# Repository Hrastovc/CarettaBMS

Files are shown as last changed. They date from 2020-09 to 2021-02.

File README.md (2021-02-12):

# CarettaBMS

CarettaBMS is the best price to performance battery management system and it's also open-source.

# Overview

In recent years, there has been an increase in the use of ultralight electric vehicles. A fairly new segment requires the use of smaller battery packs for energy storage to power vehicles. For safe use of battery packs, BMS is very important. There is a big shortage in the field of quality battery management systems, which would be suitable for smaller battery packs. Prices of the systems currently on the market are too high. The price of a BMS can exceed the price of a battery pack. The use of such BMS does not make sense. The most difficult task was to make the system as inexpensive as possible for use with smaller battery packs. Despite the low cost, BMS still has all the necessary safety mechanisms.

By approaching the challenges in a creative way it was possible to find an innovative solutions, which enabled a very low-cost implementation of the system. Analog to digital converter (ADC) is used with swapped inputs reference and ADC input. This makes it possible to measure the supply voltage without the use a of voltage divider and additional static energy consumption a voltage divider would entail. The type A standard uncertainty of cell voltage measurement is 0.9 mV. The communication uses a built-in analog comparator and two external resistors. Despite the fact that series connected modules operate on different reference potentials, this does not affect the message transmission. Tests with artificially induced interference confirmed the communication reliability of an arbitrary number of modules connected in series.

The work was released as an open source project with the name CarettaBMS. The purpose is to allow access to better quality BMS suitable for smaller battery packs to a wider audience.

# System Arhitecure

System Arhitecure

# specifications

 - Operating voltage range: od 1.8V do 5.0V
 - Operating temperature range: od 0°C do 80°C
 - Voltage measurement accuracy: ±10mV
 - Voltage measurement resolution: at least 3mV
 - Temperature measurement accuracy: ±5°C
 - PCB size: 65mm × 18mm × 5mm
 - Passive cell balancing current: 1A
 - load characteristics: R = 3.6Ω, P<sub>max</sub> = 4W
 - Maximum of series connected cells: up to 256
 - Temperature sensors: at least 3 sensors per module (1 internal, 2 external)
or up to 32 I2C sensors
 - Communication interface (cell modules with master): isolated UART 8E2
(documented protocol)
 - Bootloader for future infield firmware upgrades

# Cell Module
Cell module PCB

Schematic: https://github.com/Hrastovc/CarettaBMS/blob/master/CellModule/Hardware/CarettaBMS_CellModule0v8.pdf

# License

CarettaBMS is free software: you can redistribute it and/or modify it under the terms of the GNU General Public License version 3 as published by the Free Software Foundation.

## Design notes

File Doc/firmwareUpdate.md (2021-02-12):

---
filename: 03_firmwareUpdate
title: Firmware update
layout: main
---

To enter the bootloader send 0x62 (on 8N1 or 8E2) until you receive 0xEB response or until now response is received. To test if the mouldes are in the bootloader send 0x30 0x20 (on 8N1), if in bootloader 0x14 0x10 response should be received.

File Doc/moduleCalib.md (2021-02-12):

---
filename: 02_moduleCalib
title: Module calibibration
layout: main
---

V<sub>ref_corrected</sub> = V<sub>ref</sub> * ( V<sub>dmm</sub> / V<sub>bms</sub> )

V<sub>ref_corrected</sub> ... correction value
V<sub>ref</sub> ... ideal voltage refrance value (1500mv)
V<sub>dmm</sub> ... true cell voltage value measured with DMM (in mV)
V<sub>bms</sub> ... voltage measured reported by BMS (in mV)

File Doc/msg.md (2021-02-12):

---
filename: 08_msg
title: UART frame
layout: main
---
# UART frame

There was still the problem of how to distinguish between the commands of the control module and the responses of the cell modules. Dividing 8-bit data bytes into two messages is not desirable, so communication with nine data bits, odd parity, and one stop bit (shorter 9O1) is used. The ninth data bit allows signaling whether the message is a command or a response. The modules must execute the commands and only forward the responses. This mode of communication has been proven to be very reliable. The module always receives all message inside the interrupt routine. In case the received message is a command it needs to be saved and process later outside the interrupt. Otherwise, when you receive a reply from some other cell module, you just forward it. The 9O1 configuration is not common and is not supported by all devices. This can significantly limit the ability to use any processor in the control modules, which is not desirable. With a few smaller software solutions, we achieved that UART communication from the outside is visible as eight data bits, even parity and two stop bits (shorter 8E2). This is a much more widespread communication configuration and most processors should support it. 9O1 is still used inside the system, only on the outside it behaves like 8E2. This could only be achieved because 9O1 and 8E2 messages are the same length and have opposite parity. The picture shows us the structure of the messages in more detail. When message is received from 8E2 to 9O1, the parity bit becomes the ninth data bit. On the other hand when transmitting from 9O1 to 8E2, the ninth data bit becomes a parity bit. The downside is that this bit needs to be calculated in software, which takes some time in the interrupt routine, but it is feasible. Most likely, this kind of use of UART communication is not an example of good practice, but in this particular case it works great. The main advantage is that the user does not have to split 8-bit data bytes into two separate messages and modules can still distinguish commands from responses.

UART frame

The module always accepts the command and executes it first with an appropriate response and only then forwards the command to the next module. This ensures an easier system synchronization. In this way, we avoid race condition when the first module would already start transmitting a response and the next module is still executing the command. Interrupts should ensure this still works, but it would be a weak point of communication that can lead to CPU overload due to nesting interrupts.

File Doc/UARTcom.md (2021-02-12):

---
filename: 07_UARTcom
title: UART
layout: main
filename: UARTcom.md
---
# Non-isolated UART communication

The UART communication interface was selected as the primary communication interface. UART is a good choice mainly due to its widespread use. Communication is asynchronous, where we do not need a clock signal, so only one wire is needed between the modules. The advantage of one wire is that it is cheaper than two and also more practical in the installation of the system. The cheapest possible components and also the minimum number of components are being used to make the communication possible. The biggest problems during the design of the communication interface were caused by the protection diodes on the processor pins, but in the end we were able to exploited their purpose in some way.

## The Problem

The problem with cell modules is that processors are not powered from the same voltage source, but still have to communicate with each other. They are even powered with an offset voltages. Two neighboring processors have connected Vcc and GND pins. The model of this connection is shown in the figure below:

com. voltage devider

Lower processor (processor 2) can receive 2 different voltage levels from upper processors. The first level is at the output of logic 0 from upper processor. Upper processor reads this state as 0V, but for lower processor this is its own supply voltage or logic 1. No problems so far, we only get the reverse logic and all voltages are still in the operating range of both processors. At the second level output, logic 1 from the upper processor some problems occur. For the lower processor this level means its supply voltage plus the supply voltage of the upper processor. Now this level is no longer allowed. The voltage is just too high for lower processor. The challenge was how to adjust these two voltage levels to the lower processor so that it can easily receive the signal from the upper processor.

There are many solutions that could work, but they are not in line with the requirements. The problem is that all solutions have at least one semiconductor element. A single semiconductor element would quickly raise the cost of the required components. However with a clever use of processors peripherals, it is possible to achieve a successful communication and only with the use of two external resistors. The resistors serve as a voltage divider and limit the current through the protection diodes.

## The solution

AC unit

An build-in analog comparator (AC) is used to distinguished the signal level. The processor voltage supply is connected to the non-inverting input of the AC and 80% of the UART signal from the upper processor to the positive input. Resistors with large values were chosen for the voltage divider and for two reasons. A first, 80% of the signals voltage level is still too much for the lower processor. The current flowing through the protection diodes is limited by the use of larger resistors. Small current does not damage the diodes. The purpose of the diodes is to only keep the voltage within acceptable limits. The second reason is that we wanted to have as low static power consumption as possible, because the module is powered by a battery.

A more detailed explanation is needed to fully understand how communication works. The AC output indicates whether the UART signal voltage is less than or greater than the processor supply voltage. This is a very important piece of information that we need to get to the processor's UART receiver. The processor allows us to connect the AC output to the physical output pin of the processor. This output pin can then be easily connected to the input pin of the processor on which the UART receiver is located. However, to be able to do that, we need both one free output pin and one free input pint. Selected processor has very few pins and we don't have enough remaining free pins to make this solution feasible. A closer inspection of the "PORT" unit revealed that we only need a single processor input pin, for both signals, the rest can be solved with a  single if statement in software by changing the invert enable signal of the processors input pin.

A very similar method with the AC is used to detect zero cross of mains supply. But the described use of AC on a cell module is a bit more demanding. We didn't see anyone using an AC to trigger the UART receiver. This area of the system needed a bit more research. The solution raises two questions, "Will the communication work over the entire BMS operating voltage range from 1.8V and up to 5.0V?" and "How will communication be resistant to interference?".

## Resistor divider

Of great importance is the resistor divider division factor, which will ensure that the communication will operate in the entire voltage range of the BMS. At first, this seems like a simple problem, but like so many others, it quickly turned out to be a little more difficult. We previously mentioned that the UART signal levels from the upper module are compared to the cell voltage, which is not quite true. If that would be possible, it would be much easier. Once again it turns our we don't have enough free pins available. To overcome this problem we utilize built-in voltage reference to approximate the supply voltage. On the positive AC input is connected UART signal and on the negative input the voltage reference of 4.3V. The selected reference is the highest available in the processor. The highest reference will be the closest to supply voltage in the entire voltage range of the processor (1.8V - 5V). We don't use the reference for its true purpose, but only to give us an approximation of the supply voltage. The reference is only valid when powered by 4.8V or more. With a cell module, this will never happen. The voltage reference will always be in its "linear" range. Normally the reference is always used in the "saturated" state. In its linear range, the reference voltage output will be a few percent below the supply voltage all the time. This is very useful because the voltage reference is going to give us a sufficient approximation of the supply voltage and we do not need an additional processor input. Due to a bit different use of the voltage reference, we do not have enough data, because such use is not documented in the processors datasheet. We needed a snapshot of the reference output in the entire voltage range of the processor. The recorded characteristic is shown in the figure below.

4.3V voltage reference

The characteristic was recorded with a built-in ADC and by changing the processor supply voltage. From the characteristic, a simplified reference model was created, which is shown by the equations.





To identify a low signal level, the output from the voltage divider must be lower than the reference voltage and to detect a high level, it must be higher. These situations are described to us by inequalities:





From both inequalities we can express the divisible relation r and form one single inequality.





We can now insert real numbers into the inequality. We need to insert the voltages at which we get the smallest range of the voltage divider ratio. By solving these two inequalities, we have obtained only the range in which the division ratio must be. Due to the nonlinear characteristic of the voltage reference, the resistance tolerances and other nonlinearities of the system, this is not enough to determent the perfect dividing ratio. The use of resistors with low tolerances is also not desirable because these resistors will increase the price of the components. We even have to look at the voltage range of the system for all possible deviations of the voltage divider ratio due to resistance tolerances. For that purpose, we need equations that describe the voltage differences between the signal levels and the voltage reference. The difference between logic output 1 from the upper processor and the reference voltage of the lower processor must always be positive and vice versa for logic output 0, where the difference must always be negative. This is nicely described by the equations below:





Because the cell module uses an AC and UART receiver on the same processor input, it is important that this input always has the same and defined state. We want the processors input to always have a logical state of 1. This criterion must also be considered and is given to us by the equation:



In all three above equations we have a division ratio. Due to the resistance tolerances, the division ratio is not an exact value, but is located on the certain interval. The next equation below gives us a division ratio error due to the influence of resistance tolerances, where e<sub>1</sub> is the tolerance for R<sub>1</sub> in percent and e<sub>2</sub> for the resistance R<sub>2</sub>



With this division ratio error factor, we can extend previous inequalities. The graph in the figure below tells us all possible solutions of the inequalities. The most critical points are those closest to the X axis of the graph. The points can be identified very quickly. The critical points in the low and high signal curves must both be equidistant from the axis of the graph.

com_levels

If we combine all the conditions and insert all the parameters, we finally get a division ratio of 0.79. The division ratio can be realized using resistors from the E6 scale with 20% tolerances.

## AC output status bit as UART signal

The main problem was programmatically creating a connection between the AC status register and the UART receiver. The AC output status is written in one of the bits of the AC status register and the state of this bit needs to be transferred to the UART receiver. After analyzing the "PORT" peripheral unit, we found that the "Invert Enable" signal can be used to programmatically trigger the UART receiver.

PORT unit

We need to ensure that the signal changes quickly. This was achieved by using interrupts. Each time the AC output is changed, it triggers an interrupt. In the interrupt routine, the "Invert Enable" signal is then quickly set to the correct value. The interrupt routine used is presented in the code section below:

```C
ISR(AC0_AC_vect)
{
  /* Clear int. flag */
  AC0_STATUS = AC_CMP_bm;
  /* Invert pin input */
  if(!(AC0_STATUS & AC_STATE_bm)) PORTA_PIN7CTRL = PORT_INVEN_bm;
  else PORTA_PIN7CTRL = 0x00;
}
```

This part of the program proved that the an idea of an non-isolated UART communication works. Later on, other tests have shown that the method is also reliable.

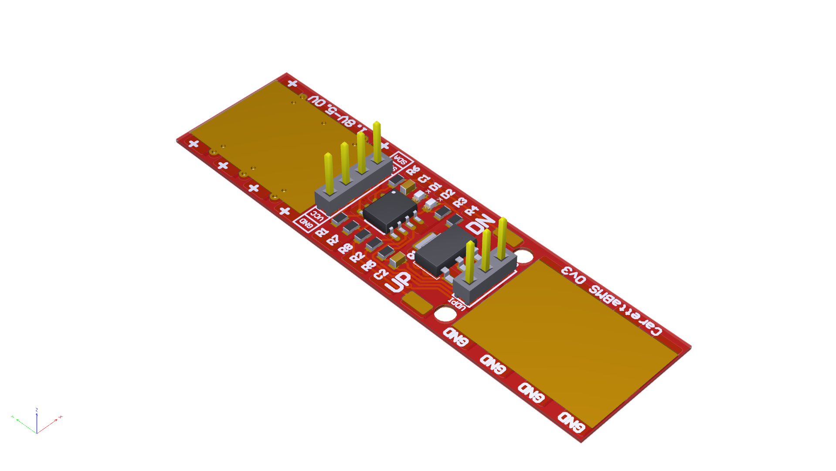
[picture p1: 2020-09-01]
CellModule/Hardware/PCB.PNG

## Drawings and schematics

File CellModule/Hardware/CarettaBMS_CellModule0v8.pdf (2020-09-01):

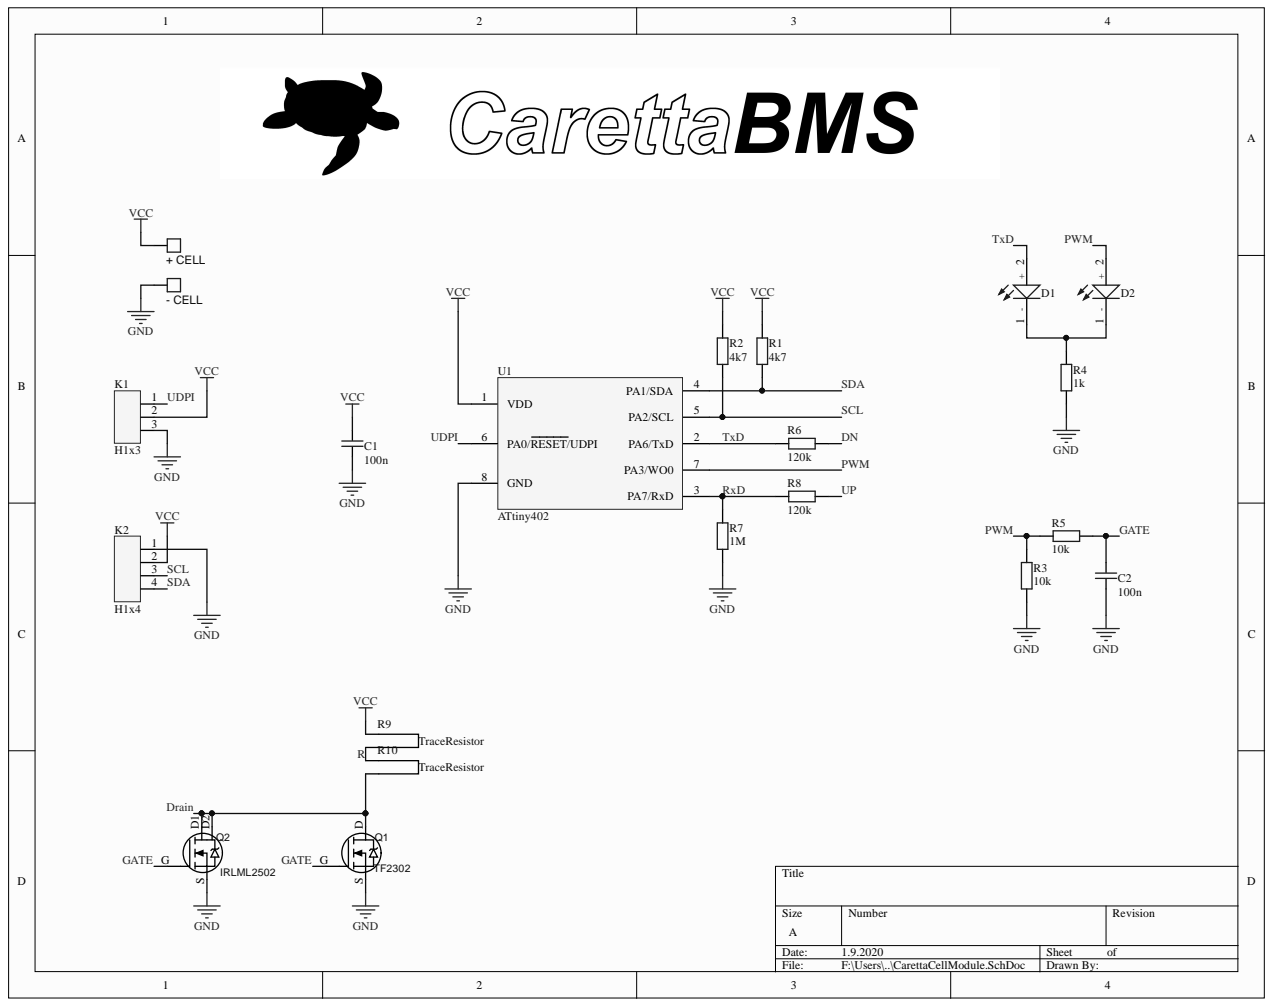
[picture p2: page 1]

Size A | Nu m ber | Revisio n

Date: 1.9.2 0 2 0 | Sheet o f
File: F:\Users\..\CarettaCellMo d ule.SchDo c | Drawn B y :

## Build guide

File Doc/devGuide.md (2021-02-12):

---
filename: 05_devGuide
title: Dev guide
layout: main
---
# Cell module source code simplified:

## State machine
```C
/* Main program entry point. */
int main(void)
{  
  /* CPUINT init */
  /* PORT init */
  /* VREF init */
  /* ADC init */
  /* AC init */
  /* USART init */
  /* TCA init */
  /* EVSYS init */
  
  /* Load settings from the EEPROM and USERROW*/
  /* Init. global variables. */
  
  /* RTC init */
  
  /* FIFO buffers init */
  
  /* Update bootloader flag, set to 0xEA to stay in the application. */
  
  /* WDT init */
  
  /* Main state machine */
  for(;;) 
  {
    /* Read new command byte. */
    uint8_t ch = readSave();
    
    if(ch == CMD_ALARM_CODES)
    {
      /* Handle command */
    }
    else if(ch == CMD_GOTO_BOOTLOADER)
    {
      /* Handle command */
    }
    else
    {
      /* Unknown command, respond with error code. */
      /* Delete received command, we dont want to forwad bad commands. */
    }
    
    /* Forward command, no need if this is the last module. */
  }
}
```

```C
uint8_t readSave(void)
{
  /* Wait for a new byte received. */
  uint8_t ch = readWait();
  /* Save byte (ch) to the command buffer. */
  /* Return received byte (ch). */
  return ch;
}
```

```C
uint8_t readWait(void)
{
  /* Do the work while no new data was received. */
  do 
  {
    /* Wait for the real time conter compare event; every  */
    if((RTC_INTFLAGS & RTC_CMP_bm))
    {
      /* Do the work */
      task(&settings);
    }
  }
  while(!FIFOavailable(&RXfifo));
  
  /* New data received, now return the received data. */
  return FIFOread(&RXfifo);
}
```

Task function performs all the main operations of the cell module BMS.
```C
void task(tSettings *p)
{
  /* Sample two external inputs. */
  /* Sample internal temperature sensor. */
  
  /* Check for overvoltage condition */
  /* Check for charged condition */
  /* Check for empty condition */
  /* Check for undervoltage condition */
  /* Check for overtemperature condition */
  /* Balance cell, if needed apply balancing current. */
  
  /* Send all the alarms, if any occurred. */
  
  /* If undervoltage condition go to sleep.
   * else if empty condition or sleep requested go to standby mode.
   */
  
  /* Call watchdog timer. */
}
```

All the received commands are saved in a buffer. Once the command has been handled buffer with the command is forwarded to the next module. But if this is the bottom module commands don't need to be forwarded.

```C
void forwardBufferIfNotBot(void)
{
  /* Is this the bottom module? */
  if(!settings.moduleNum)
  {
    /* Delete received command, we dont want to forwad the command. */
  }
  else
  {
    /* Forward received command. */
  }
}
```

## Communication
```C
void respond(uint8_t data)
{
  /* Is this the bottom module? */
  if(!settings.moduleNum)
  {
    /* Calculate parity bit. */
  }
  
  /* Wait for UART to be ready to send data. */
  
  /* Is this the bottom module? */
  if(!settings.moduleNum)
  { 
    /* Set ninth data bit as parity bit, this converts from 9O1 to 8E2. */
  }
  else
  {
    /* Set ninth data bit to zero, this indicates data is a response. */
  }
  
  /* Send data */
}
```

```C
void forward(uint8_t data)
{
  /* Wait for UART to be ready to send data. */
  /* Set ninth data bit to one, this indicates data is a command. */
  /* Send data */
}
```

```C
ISR(AC0_AC_vect)
{
  /* Clear int. flag */
  /* Set invert enable signal depending on AC state to trigger UART receiver. */
}
```

```C
ISR(USART0_RXC_vect)
{
  /* Read UART status registers. */
  
  /* Has frame or parity error occurred? */
  if(status & (USART_FERR_bm | USART_PERR_bm))
  {
    /* Create frame, parity alarm. */
    /* Send all the alarms. */
    /* Something went wrong, reset itself. */
  }
  /* Has receive complete interrupt occurred? */
  else if(status & USART_RXCIF_bm)
  {
    /* Is this a command? */
    if((status & 0x01) | settings.topModule)
    {
      /* Save the command, so it can be handled outside the ISR. */
    }
    /* This is a respone(not a command). */
    else
    {
      /* Respond with the data. */
    }
  }
}
```

## Voltage measurement
```C
ISR(ADC0_RESRDY_vect)
{
  /* Convert new ADC sample to voltage measurement. */
}
```

## Sleep
```C
void goToSleep(uint8_t mode)
{
  /* Make measure interval short, so we measure as soon as we wake up. */
  /* Wait for any outgoing transmitions to finish. */
  /* Enable PIN1 interrupt (wake up source). */
  /* Enable sleep mode. */
  /* Connect AC output to the PIN3 (UART signal change triggers PIN3 interrupt.)*/
  /* Go to sleep. */
  /* Clear the real time counter compare int. flag (wake up source). */
}
```

```C
ISR(PORTA_PORT_vect)
{
  /* Disconnect AC output to the PIN3 (needs to be done as soon as possible). */
  /* Disable PIN3 interrupt (wake up source). */
  /* Clear int. flag. */
}
```

```C
ISR(RTC_PIT_vect)
{
  /* Disconnect AC output to the PIN3 (needs to be done as soon as possible). */
  /* Disable PIN3 interrupt (wake up source). */
  /* Clear int. flag. */
}
```

```C
ISR(RTC_CNT_vect)
{
  /* Clear the int. flag. */
  /* If sleep was not requested an error has occurred, create alarm. */
  /* Send all the alarms */
  /* Something went wrong, reset itself. */
}
```

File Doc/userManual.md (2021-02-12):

---
filename: 01_userManual
title: User manual
layout: main
---

placeholder

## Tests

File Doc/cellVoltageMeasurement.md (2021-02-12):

---
filename: 06_cellVoltageMeasurement
title: Voltage measurement
layout: main
---
# CarettaBMS cell voltage measurement

The voltage measurement is heavily **cost-optimized**. Optimization was enabled due to some of the options offered by the processors ADC. For cell voltage measurement no external components are required. Although to achieve the performance needed, this measurement method required some additional software solutions.

## ADC configuration

The processor has a 10-bit analog-to-digital converter (ADC) and some voltage references. The voltage references are not very accurate, but they are stable, which is important. During the production, it is necessary to calibrate the modules, so the exact value of the voltage reference is known. Typically, an ADC is used by connecting a voltage reference to its reference input and an unknown voltage, we want to measure, to its input. The input voltage we want to measure must always be lower than the reference voltage. In this case, the reference voltage used has an output of 1.5V, because it is the only available reference in the entire processor's power supply range. If this reference voltage were to be connected to the ADC's reference input, the maximum allowed voltage at the input would be less than 1.5V. There lies our problem as we want to measure the voltage range between 1.8V and 5V. The problem could be resolved by using a voltage divider at the ADC's input, but this solution is not acceptable as it has two major drawbacks. Due to the voltage divider, we would introduce additional static energy consumption, undesirable in battery applications. Although this could still be mitigated in some way by using a larger values resistors to limit the current. I think the bigger problem is the cost that two additional resistors would contribute too. The voltage measurement must be accurate to at least ±10mV and the resistors needed to achieve that accuracy are expensive. All of this led me to a different, lesser-known approach of using an ADC. Instead of connecting the reference voltage to the ADC reference input, cell voltage was connected to it. In the case of CarettaBMS, this is also the supply voltage of the processor. This now means that any voltage in the range between 0V and the processor supply can be measured at the ADCs input. It would make sense to connect a known value to the input, such as a voltage reference of 1.5V. The voltage will always be lower than the processor's power supply. This way of measuring has been used many times but is not well known and it's not common. The important thing is that ADC always operates within its own operating parameters.

## ADC resolution

As this ADC configuration use is not widespread or well documented, there is no data on the accuracy and resolution of the measurement. For a BMS, these two are crucial. We need to take a closer look at the equations that describe how the ADC works. Of particular importance is the resolution of the measurement, which turns out to have a significant nonlinear dependence on the cell voltage.

Below equation typically describes the operation of the ADC and is often used to convert the ADC output data back to the input voltage:



We assume that the reference voltage V<sub>ref</sub> is a constant and we have a constant number of ADC bits (m). Only the ADC result (n) remains in the equation. This gives the classical linear equation, whit the linear dependence of the ADC result on the input voltage. We can also quickly recognize the resolution of the ADC, which is given as a fraction of the reference voltage or U<sub>ref</sub> / 2^m. Due to the unusual ADC configuration, where the quantities at the inputs of the ADC are swapped, we need to do the same in the previous equation. We get a new equation that describes the operation of the ADC in the current configuration:



We would prefer to rearrange the new equation to be more like the first one because we want to calculate U<sub>in</sub> from the ADC result:



By the same analysis as we performed on the first equation, we can replace U<sub>ref</sub> and m by constants. The measured voltage no longer has a linear dependence on the ADC result. The equation no longer shows us the ADC resolution as the first equation did. Now, the path to the equation that describes the ADC resolution is much more difficult as the resolution changes. The resolution depends on the cell voltage. Briefly, we would summarize that the larger the difference between the reference voltage and the cell voltage, the lower the resolution. To facilitate the derivation of the equation, a simple mathematical model of the ADC was developed, where the two input quantities were replaced ([model](https://www.desmos.com/calculator/vjn2ooxamo)). The model has contributed greatly to a better understanding of ADC performance. The conclusion is that the resolution of the ADC is equal to the difference between the next ADC result, when we increase the voltage, and the current result. This is also described by the next equation:

 

We further transform the equation to obtain a single fraction. This gives the equation:



This equation describes how the resolution changes depending on the ADC result. To express the resolution of the ADC as a function of the input voltage U<sub>in</sub>, we replace the ADC result (n) in the equation with the second equation. In doing so, we must take into account the property of the quantizer and the ADC result is always a natural number or 0. This is achieved with the floor function and an additional offset factor (o) that defines the operation of the ADC around the result 0. This factor can be 0 or 0.5. In this case, the offset factor is 0.

 

When all parameters are inserted into the equation, it turns out that the ADC does not have a sufficient number of bits to achieve the sufficient resolution and consequently the accuracy specified in the requirements. However, the use of ADC in the described configuration was chosen because the cost is very important. In this configuration, no external components are required. The resolution problem was later solved in the program by oversampling the ADC, thus achieving the required measurement resolution.

## Resolution plot

resolution plot

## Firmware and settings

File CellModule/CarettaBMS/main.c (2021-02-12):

/****************************************************************************************
 *   _____                         _     _             ____    __  __    _____ 
 *  / ____|                       | |   | |           |  _ \  |  \/  |  / ____|
 * | |        __ _   _ __    ___  | |_  | |_    __ _  | |_) | | \  / | | (___  
 * | |       / _` | | '__|  / _ \ | __| | __|  / _` | |  _ <  | |\/| |  \___ \ 
 * | |____  | (_| | | |    |  __/ | |_  | |_  | (_| | | |_) | | |  | |  ____) |
 *  \_____|  \__,_| |_|     \___|  \__|  \__|  \__,_| |____/  |_|  |_| |_____/ 
 *
 ***************************************************************************************/

/************************************************************************************//**
* \file       main.c
* \brief      CarettaBMS, Open source BMS
* \internal
*----------------------------------------------------------------------------------------
*                                    L I C E N S E
*----------------------------------------------------------------------------------------
* This file is part of CarettaBMS. CarettaBMS is free software: you can redistribute it
* and/or modify it under the terms of the GNU General Public License version 3 as
* published by the Free Software Foundation.
*
* CarettaBMS is distributed in the hope that it will be useful, but WITHOUT ANY WARRANTY;
* without even the implied warranty of MERCHANTABILITY or FITNESS FOR A PARTICULAR
* PURPOSE. See the GNU General Public License for more details.
*
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
* \endinternal
****************************************************************************************/


/****************************************************************************************
* Include files
****************************************************************************************/
#include <avr/io.h>
#include <avr/interrupt.h>
#include <avr/eeprom.h>
#include "CarettaBMS_CMD.h"
#include "command.h"
#include "FIFO.h"


/****************************************************************************************
* Macro definitions
****************************************************************************************/
#define F_CPU (3333333333)

#define RX_BUFFER_SIZE 16
#define TX_BUFFER_SIZE 16

#define ALARM_BUFFER_SIZE 8

#define readUserRow(x) (*x)

#define UR_BOOTLOADER_CONDITION_ADDR ((volatile uint8_t  *)(&USERROW_USERROW0 + 31))
#define UR_MODULE_NUMBER_ADDR        ((volatile uint8_t  *)(&USERROW_USERROW0 + 30))

#define RESP_OK                      (uint8_t)(0x0F)

#define ERROR_UNKNOWN_COMMAND        (uint8_t)(0xEA)
#define ERROR_SEQUENCE               (uint8_t)(0xEA)

#define ALARM_OVER_TEMP              (uint8_t)(0xA0)
#define ALARM_CPU_OUTATIME           (uint8_t)(0xA1)
#define ALARM_RTC_OVERFLOW           (uint8_t)(0xA2)
#define ALARM_OVERVOLTAGE            (uint8_t)(0xA3)
#define ALARM_CELL_CHARGED           (uint8_t)(0xA4)
#define ALARM_CELL_EMPTY             (uint8_t)(0xA5)
#define ALARM_UNDERVOLTAGE           (uint8_t)(0xA6)
#define ALARM_FRAME_PARITY           (uint8_t)(0xA7)

#define USE_I2C


/****************************************************************************************
* Type definitions
****************************************************************************************/
typedef struct
{
  /* Parameters */
  volatile uint16_t vrefCalibrated;
  volatile uint16_t balanceCurrent;
  volatile uint16_t maxTempBMS;
  volatile uint16_t maxTempBMSRecover;
  volatile uint16_t voltLimitHigh;
  volatile uint16_t voltLimitHighRecover;
  volatile uint16_t voltageCharged;
  volatile uint16_t voltageChargedRecover;
  volatile uint16_t voltageEmpty;
  volatile uint16_t voltageEmptyRecover;
  volatile uint16_t voltLimitLow;
  volatile uint16_t voltLimitLowRecover;
  volatile uint16_t measureInterval;
  volatile uint16_t voltBalanceStart;
  volatile uint16_t voltBalanceStop;
  volatile uint16_t balanceHysteresis;
  volatile uint8_t sleepRequested;
  /* program global variables */
  volatile uint8_t moduleNum;
  volatile uint8_t topModule;
  volatile uint16_t targetVoltage;
  volatile uint32_t cellVoltage;
  volatile uint16_t intTemp;
  volatile uint16_t ADCextInput[2];
}tSettings;


/****************************************************************************************
* Function prototypes
****************************************************************************************/
//void task(void);
void syncResponse(void);
void setBalancingCurrent(uint8_t current);
void watchdogConfig(uint8_t x);
void goToBootloader(void);
void goToSleep(uint8_t mode);
void calcVoltageReading(void);
uint16_t takeADCreading(void);
uint8_t readWait(void);
void respondIfBot(uint8_t ch);
void respondIfNotBot(uint8_t ch);
void respond(uint8_t data);
void respondTwoBytes(uint16_t data);
void forwardBufferIfNotBot(void);
void forward(uint8_t data);
uint8_t readSave(void);
void resetProcessor(void);
void twoByteParameter(volatile uint16_t *parameter);
void writeUserRow1byte(volatile uint8_t *addr, uint8_t val);
void emptyAlarmQ(void);
void createAlarm(uint8_t code);
void respondOK(uint8_t respSize);
void respondOKnoPayload(void);
void emptyOutgoingBuffer(void);
void setMeasureInterval(uint16_t interval);
void task(tSettings *p);
void ADCset1V5refMuxIntRef(void);
void ADCtriggers(uint8_t state);


/****************************************************************************************
* Local data declaration
****************************************************************************************/
FIFO_t RXfifo;
uint8_t RXbuffer[RX_BUFFER_SIZE];

FIFO_t TXfifo;
uint8_t TXbuffer[TX_BUFFER_SIZE];

FIFO_t alarmQ;
uint8_t alarmBuffer[ALARM_BUFFER_SIZE];

tSettings EEMEM defaultSettings = {
  1500,  //vrefCalibrated
    10,  //balanceCurrent
    60,  //maxTempBMS
     5,  //maxTempBMSRecover
  4300,  //voltLimitHigh
  4200,  //voltLimitHighRecover
  4200,  //voltageCharged
  4150,  //voltageChargedRecover
  3200,  //voltageEmpty
  3300,  //voltageEmptyRecover
  2500,  //voltLimitLow
  2600,  //voltLimitLowRecover
  1000,  //measureInterval
  3600,  //voltBalanceStart
  4300,  //voltBalanceStop
    50,  //balanceHysteresis
     0,  //sleepRequested
     0,  //moduleNum
     0,  //topModule
  5000,  //targetVoltage
     0,  //cellVoltage
     0,  //intTemp
 {0, 0}  //ADCextInput[2]
};

tSettings EEMEM storedSettings = {
  1500,  //vrefCalibrated
    10,  //balanceCurrent
    60,  //maxTempBMS
     5,  //maxTempBMSRecover
  4300,  //voltLimitHigh
  4200,  //voltLimitHighRecover
  4200,  //voltageCharged
  4150,  //voltageChargedRecover
  3200,  //voltageEmpty
  3300,  //voltageEmptyRecover
  2500,  //voltLimitLow
  2600,  //voltLimitLowRecover
  1000,  //measureInterval
  3600,  //voltBalanceStart
  4300,  //voltBalanceStop
    50,  //balanceHysteresis
     0,  //sleepRequested
     0,  //moduleNum
     0,  //topModule
  5000,  //targetVoltage
     0,  //cellVoltage
     0,  //intTemp
 {0, 0}  //ADCextInput[2]
};

tSettings settings;


/************************************************************************************//**
** \brief     This is main program entry point
**
****************************************************************************************/
int main(void)
{
  cli();
  
  /* CPUINT init */
  CPUINT_LVL1VEC = AC0_AC_vect_num;
  
  /* PORT init */
  /* PA3 -> PWM, PA6 -> TxD */
  PORTA_DIRSET = PIN3_bm | PIN6_bm;
  PORTA_PIN6CTRL = PORT_INVEN_bm;
  
  /* VREF init */
  /* Moved to ADCset1V5refMuxIntRef() */
  //VREF_CTRLA = VREF_ADC0REFSEL_1V5_gc | VREF_DAC0REFSEL_4V34_gc;
  
  /* ADC init */
  ADCset1V5refMuxIntRef();
  ADCtriggers(1);
  ADC0_CTRLB = 0x04; //ACC16
  ADC0_CTRLD = ADC_INITDLY_DLY32_gc | ADC_ASDV_ASVON_gc | 0x02;
  ADC0_CTRLA = ADC_ENABLE_bm;
  
  /* AC init */
  AC0_MUXCTRLA = AC_MUXNEG_VREF_gc | AC_INVERT_bm;
  AC0_CTRLA = AC_RUNSTDBY_bm | AC_HYSMODE_50mV_gc | AC_ENABLE_bm;
  AC0_INTCTRL = AC_CMP_bm;
  
  /* USART init */
  USART0_CTRLA = USART_RXCIE_bm;
  USART0_CTRLB = USART_RXEN_bm | USART_TXEN_bm;
  USART0_CTRLC |= USART_PMODE_ODD_gc | USART_CHSIZE_9BITL_gc;
  USART0_BAUD = 1389;
  
  /* TCA init */
  TCA0_SINGLE_CTRLB = TCA_SINGLE_WGMODE_SINGLESLOPE_gc | TCA_SINGLE_CMP0EN_bm;
  TCA0_SINGLE_PER = 102;
  TCA0_SINGLE_CMP0 = 0;
  TCA0_SINGLE_CTRLA = TCA_SINGLE_CLKSEL_DIV256_gc | TCA_SINGLE_ENABLE_bm;
  
  /* EVSYS init */
  EVSYS_SYNCCH0 = EVSYS_SYNCCH0_TCA0_CMP0_gc;
  EVSYS_ASYNCUSER1 = EVSYS_ASYNCUSER1_SYNCCH0_gc;
  
  /* Load settings */
  eeprom_read_block(&settings, &storedSettings, sizeof(tSettings));
  
  /* Read user row */
  settings.moduleNum = readUserRow(UR_MODULE_NUMBER_ADDR);
  
  /* Init. global variables. */
  settings.targetVoltage = 5000;
  
  /* RTC init */
  RTC_CLKSEL = RTC_CLKSEL_INT1K_gc;
  RTC_INTCTRL = RTC_OVF_bm;
  RTC_PITINTCTRL = RTC_PI_bm;
  while(RTC_PITSTATUS & RTC_CTRLBUSY_bm);
  RTC_PITCTRLA = RTC_PERIOD_CYC32768_gc | RTC_PITEN_bm;
  /* 25ms in required for the ADC to take 2 measurement, before running task for the first time. */
  setMeasureInterval(settings.measureInterval);
  while(RTC_STATUS & RTC_CTRLABUSY_bm);
  RTC_CTRLA = RTC_RUNSTDBY_bm | RTC_RTCEN_bm;
  
  /* FIFO init */
  FIFOinit(&RXfifo, RXbuffer, RX_BUFFER_SIZE);
  FIFOinit(&TXfifo, TXbuffer, TX_BUFFER_SIZE);
  FIFOinit(&alarmQ, alarmBuffer, ALARM_BUFFER_SIZE);
  
  /* Update bootloader flag */
  writeUserRow1byte(UR_BOOTLOADER_CONDITION_ADDR, 0xEA);
  
  /* WDT init */
  watchdogConfig(WDT_PERIOD_4KCLK_gc);
  
  sei();
  
  for(;;) 
  {
    uint8_t ch = readSave();
    
    /* Reads all the alarm codes from one of the module, TODO: handle alarm codes */
    if(ch == CMD_ALARM_CODES)
    {
      /* read alarm source module number */
      uint8_t sourceModule = readSave();
      /* read the number of alarm codes send */
      uint8_t len = readSave();
      /* read all the codes */
      do readSave();
      while(--len);
      /* Forward alarm,
       * except if the circle was completed and you were the source of the alarm.
       */
      if(sourceModule == settings.moduleNum)
      {
        emptyOutgoingBuffer();
      }
      else
      {
        do 
        {
          forward(FIFOread(&TXfifo));
        }
        while(FIFOavailable(&TXfifo));
      }
    }
    
    /* Command to go to the bootloader */
    else if(ch == CMD_GOTO_BOOTLOADER)
    {
      writeUserRow1byte(UR_BOOTLOADER_CONDITION_ADDR, 0xEB);
      if(!settings.moduleNum) respond(0xEB);
      forwardBufferIfNotBot();
      resetProcessor();
    }
    
    /* New voltage reference calibration value */
    else if(ch == CMD_VOLTAGE_CAL)
    {
      if(settings.moduleNum == readSave())
      {
        twoByteParameter(&settings.vrefCalibrated);
        emptyOutgoingBuffer();
      }
      else
      {
        readSave();
        readSave();
      }
    }
    
    /* New balance current limit value */
    else if(ch == CMD_BALANCE_CURRENT)
    {
      twoByteParameter(&settings.balanceCurrent);
    }
    
    /* Respond with all the external temperatures. */
    else if(ch == CMD_EXT_INPUTS)
    {
      respondOK(0x04);
      for(uint8_t i; i < 2; i++)
      {
        respond((uint8_t)settings.ADCextInput[i]);
        respond((uint8_t)(settings.ADCextInput[i] >> 8));
      }
    }
    
    /*  */
    else if(ch == CMD_MAX_TEMP_BMS)
    {
      twoByteParameter(&settings.maxTempBMS);
    }
    
    /*  */
    else if(ch == CMD_MAX_TEMP_RECOVER)
    {
      twoByteParameter(&settings.maxTempBMSRecover);
    }
    
    /*  */
    else if(ch == CMD_HIGH_VOLT_LIMIT)
    {
      twoByteParameter(&settings.voltLimitHigh);
    }
    
    /*  */
    else if(ch == CMD_HIGH_VOLT_RECOVER)
    {
      twoByteParameter(&settings.voltLimitHighRecover);
    }
    
    /*  */
    else if(ch == CMD_CHARGED_VOLTAGE)
    {
      twoByteParameter(&settings.voltageCharged);
    }
    
    /*  */
    else if(ch == CMD_CHARGED_RECOVER)
    {
      twoByteParameter(&settings.voltageChargedRecover);
    }
    
    /*  */
    else if(ch == CMD_EMPTY_VOLTAGE)
    {
      twoByteParameter(&settings.voltageEmpty);
    }
    
    /*  */
    else if(ch == CMD_EMPTY_RECOVER)
    {
      twoByteParameter(&settings.voltageEmptyRecover);
    }
    
    /*  */
    else if(ch == CMD_LOW_VOLT_LIMIT)
    {
      twoByteParameter(&settings.voltLimitLow);
    }
    
    /*  */
    else if(ch == CMD_LOW_VOLT_RECOVER)
    {
      twoByteParameter(&settings.voltLimitLowRecover);
    }
    
    /*  */
    else if(ch == CMD_GOTO_SLEEP)
    {
      settings.sleepRequested = 0x01;
      respondOKnoPayload();
    }
    
    /*  */
    else if(ch == CMD_TOP_MODULE)
    {
      settings.topModule = 0x01;
      respondOKnoPayload();
      emptyOutgoingBuffer();
      forward(CMD_NOT_TOP_MODULE);
    }
    
    /*  */
    else if(ch == CMD_NOT_TOP_MODULE)
    {
      settings.topModule = 0x00;
      respondOKnoPayload();
    }
    
    /*  */
    else if(ch == CMD_MEASURE_INTERVAL)
    {
      twoByteParameter(&settings.measureInterval);
      setMeasureInterval(settings.measureInterval);
    }
    
    /* Set the new module number */
    else if(ch == CMD_NMBR_OF_MODULES)
    {
      settings.moduleNum = readWait() - 1;
      writeUserRow1byte(UR_MODULE_NUMBER_ADDR, settings.moduleNum);
      FIFOaddToBuffer(&TXfifo, settings.moduleNum);
      respondOKnoPayload();
    }
    
    /*  */
    else if(ch == CMD_BALANCE_START)
    {
      twoByteParameter(&settings.voltBalanceStart);
    }
    
    /*  */
    else if(ch == CMD_BALANCE_STOP)
    {
      twoByteParameter(&settings.voltBalanceStop);
    }
    
    /*  */
    else if(ch == CMD_BALANCE_HYSTERESIS)
    {
      twoByteParameter(&settings.balanceHysteresis);
    }
    
    /*  */
    else if(ch == CMD_RESET_SETTINGS)
    {
      eeprom_read_block(&settings, &defaultSettings, sizeof(tSettings));
      settings.moduleNum = readUserRow(UR_MODULE_NUMBER_ADDR);
      eeprom_write_block(&settings, &storedSettings, sizeof(tSettings));
      setMeasureInterval(settings.measureInterval);
      respondOKnoPayload();
    }
    
    /* Take module to sleep */
    else if(ch == CMD_SAVE_SETTINGS)
    {
      eeprom_write_block(&settings, &storedSettings, sizeof(tSettings));
      respondOKnoPayload();
    }
    
    /* Respond with temperature reading of processors internal sensor. */
    else if(ch == CMD_INT_TEMPERATURE)
    {
      //respondOK(0x02);
      respondTwoBytes(settings.intTemp);
    }
    
    /*  */
    else if(ch == CMD_TARGET_VOLTAGE)
    {
      twoByteParameter(&settings.targetVoltage); 
    }
    
    /* Respond with the cell voltage */
    else if(ch == CMD_CELL_VOLTAGE)
    {
      while(!settings.cellVoltage);
      //respondOK(0x02);
      respondTwoBytes(settings.cellVoltage);
    }
    
    /* Do nothing, just sync for all the modules to wake up. */
    else if(ch == CMD_WAKE_UP_SYNC)
    {
      settings.sleepRequested = 0x00;
      respondOKnoPayload();
    }
    
#ifdef USE_I2C
    
    /*  */
    else if(ch == CMD_TWI_INIT)
    {
      if(settings.moduleNum == readSave())
      {
        respondOKnoPayload();
        /* 100kHz @ 3.33MHz per. clk. */
        TWI0_MBAUD = 10;
        /* Enable TWI as master without any interrupts. */
        TWI0_MCTRLA = TWI_ENABLE_bm;
        /* Writing 0x1 to the BUSSTATE bits forces the bus state logic into its Idle state. */
        TWI0_MSTATUS = TWI_BUSSTATE_IDLE_gc;
        emptyOutgoingBuffer();
      }
    }
    
    /*  */
    else if(ch == CMD_TWI_STATUS)
    {
      if(settings.moduleNum == readSave())
      {
        respondOK(0x01);
        respond(TWI0_MSTATUS);
        emptyOutgoingBuffer();
      }
    }
    
    /*  */
    else if(ch == CMD_TWI_START)
    {
      if(settings.moduleNum == readSave())
      {
        uint8_t address = readSave();
        uint8_t rdWr = readSave();
        if(rdWr > 0x01) respond(ERROR_SEQUENCE);
        else
        {
          respondOK(0x01);
          /* Send START condition */
          TWI0_MADDR = (uint8_t)(address << 1) | (rdWr & 0x01);
          /* Wait for write or read interrupt flag */
          while(!(TWI0_MSTATUS & (TWI_WIF_bm | TWI_RIF_bm)));
          /* Error on bus, return 0x00. */
          if(TWI0_MSTATUS & TWI_ARBLOST_bm) respond(0x00);
          /* Return true if slave gave an ACK */
          respond(!(TWI0_MSTATUS & TWI_RXACK_bm));
        }
        emptyOutgoingBuffer();
      }
      else
      {
        readSave();
        readSave();
      }      
    }
    
    /*  */
    else if(ch == CMD_TWI_STOP)
    {
      if(settings.moduleNum == readSave())
      {
        respondOKnoPayload();
        /* Send STOP */
        TWI0_MCTRLB = TWI_ACKACT_bm | TWI_MCMD_STOP_gc;
        emptyOutgoingBuffer();
      }
    }
    
    /*  */
    else if(ch == CMD_TWI_WRITE)
    {      
      if(settings.moduleNum == readSave())
      {
        uint8_t data = readSave();
        respondOK(0x01);
        /* Wait for write complete interrupt flag */
        while(!(TWI0_MSTATUS & TWI_WIF_bm));
        /* Copy data to master data register. */
        TWI0_MDATA = data;
        /* Transmit Data */
        TWI0_MCTRLB = TWI_MCMD_RECVTRANS_gc;
        /* Return true if slave gave an ACK */
        respond(!(TWI0_MSTATUS & TWI_RXACK_bm));
        emptyOutgoingBuffer();
      }
      else
      {
        readSave();
      }
    }
    
    /*  */
    else if(ch == CMD_TWI_READ)
    {
      if(settings.moduleNum == readSave())
      {
        uint8_t nack = readSave();
        if(nack > 0x01) respond(ERROR_SEQUENCE);
        else
        {
          respondOK(0x01);
          /* Wait for read complete interrupt flag */
          while(!(TWI0_MSTATUS & TWI_RIF_bm));
          /* Copy data from master data register. */
          uint8_t data = TWI0_MDATA;
          /* Last byte to be read, send NACK. */
          //if(!ack) TWI0_MCTRLB = TWI_ACKACT_bm | TWI_MCMD_RECVTRANS_gc;
          /* Execute Acknowledge Action succeeded by a byte read operation. */
          //else TWI0_MCTRLB = TWI_MCMD_RECVTRANS_gc;
          TWI0_MCTRLB = (nack << TWI_ACKACT_bp) | TWI_MCMD_RECVTRANS_gc;
          /* Return received data byte */
          respond(data);
        }        
        emptyOutgoingBuffer();
      }
      else
      {
        readSave();
      }
    }
    
#endif // USE_I2C
    
    /* Unknown command, respond with error code. */
    else
    {
      respond(ERROR_UNKNOWN_COMMAND);
      emptyOutgoingBuffer();
    }
    
    forwardBufferIfNotBot();
  }
} /*** end of main ***/


void respondOK(uint8_t respSize)
{
  respond(RESP_OK);
  respond(respSize);
}


void respondOKnoPayload(void)
{
  respond(RESP_OK);
  respond(0x00);
}


void emptyOutgoingBuffer(void)
{
  FIFOflush(&TXfifo);
} 


void setMeasureInterval(uint16_t interval)
{
  /* Reset counter in case new interval is shorter than the last one. */
  RTC_CNT = 0x0000;
  RTC_CMP = interval;
  /* Interval should be limited to 60.000 (1min), to ensure RTC_PER doesn't overflows. */
  RTC_PER = interval + 100;
}


void createAlarm(uint8_t code)
{
  FIFOaddToBuffer(&alarmQ, code);
}


void emptyAlarmQ(void)
{
  if(FIFOavailable(&alarmQ))
  {
    forward(CMD_ALARM_CODES);
    forward(settings.moduleNum);
    forward(FIFOavailable(&alarmQ));
    do 
    {
      forward(FIFOread(&alarmQ));
    }
    while(FIFOavailable(&alarmQ));
  }
}


void ADCset1V5refMuxIntRef(void)
{
  VREF_CTRLA = VREF_ADC0REFSEL_1V5_gc | VREF_DAC0REFSEL_4V34_gc;
  ADC0_CTRLC = ADC_SAMPCAP_bm | ADC_REFSEL_VDDREF_gc | ADC_PRESC_DIV2_gc;
  ADC0_MUXPOS = ADC_MUXPOS_INTREF_gc;
}


void ADCtriggers(uint8_t state)
{
  if(!state)
  {
    /* Disable triggers. */
    ADC0_INTCTRL = 0x00;
    ADC0_EVCTRL = 0x00;
  }
  else
  {
    /* Enable triggers. */
    ADC0_EVCTRL = ADC_STARTEI_bm;
    ADC0_INTCTRL = ADC_RESRDY_bm;
  }
}
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
